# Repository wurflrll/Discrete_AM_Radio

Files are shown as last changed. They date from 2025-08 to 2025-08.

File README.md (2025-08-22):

# Discrete AM Radio

## 27MHz AM Radio from Discrete Components

# Descriptions
This project comprises two different PCBs, a Receiver and Transmitter.  The circuits rely on basic BJT amplifier designs, a 27MHz oscillator.

## Added Files
This contains all the files from my two KiCad project and the BOMS (factory assembled unlike Sawtooth generator project).

## Problems
Crystal Oscillator has issues because the loop gain is too high, due to a mispredicted Q factor of
the crystal.

Trying to use a simple op-amp circuit for the preamplification of the microphone signal was a bad idea.  
The NCS20072D is simply too high noise, especially for a high gain pre-amp from a ~-50dB microphone.

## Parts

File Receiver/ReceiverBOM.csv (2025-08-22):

Id | Designator | Footprint | Quantity | Designation | Supplier and ref
1 | R2,R21 | R_0603_1608Metric | 2 | 2.2K | C114662
2 | R12,R20 | R_0603_1608Metric | 2 | 5.1K | C105580
3 | C16 | C_Radial_D8.0mm_H11.5mm_P3.50mm | 1 | 220uF | C107639
4 | C20,C3,C17,C19,C5,C11,C15,C2,C1,C6,C4,C14,C18,C7 | C_0603_1608Metric | 14 | 10uF | C19702
5 | RV2,RV3,RV1 | Potentiometer_Bourns_3386P_Vertical | 3 | R_Potentiometer | C48642119
6 | R6,R24,R16,R13,R22,R4 | R_0603_1608Metric | 6 | 100R | C105588
7 | C10,C12 | C_0603_1608Metric | 2 | 51pF | C107051
8 | R14,R15,R7,R9,R27,R8 | R_0603_1608Metric | 6 | 10K | C98220
9 | Q3,Q6,Q7,Q8,Q4,Q1,Q9 | SOT-23 | 7 | Q_NPN_BEC | C3199172
10 | R18,R25 | R_0603_1608Metric | 2 | 100K | C14675
11 | R19,R1 | R_0603_1608Metric | 2 | 3.16K | C2930087
12 | C8,C13 | C_0603_1608Metric | 2 | 10nF | C100042
13 | R26 | R_0603_1608Metric | 1 | 22K | C31850
14 | R11 | R_0603_1608Metric | 1 | 332K | C4351218
15 | R17 | R_0603_1608Metric | 1 | 51K | C107231
16 | U2 | SOIC-8_3.9x4.9mm_P1.27mm | 1 | LM386 | C23573
17 | R10 | R_0603_1608Metric | 1 | 110K | C2906984
18 | TP3,TP2,TP4,TP5 | TestPoint_Loop_D2.50mm_Drill1.0mm | 4 | LOOP | C5199815
19 | C9 | C_0603_1608Metric | 1 | 68pF | C62782
20 | L1 | L_Axial_L12.0mm_D5.0mm_P15.24mm_Horizontal_Fastron_MISC | 1 | 4.7mH | C2931871
21 | R23 | R_0603_1608Metric | 1 | 1K | C22548
22 | U1 | SOIC-8_3.9x4.9mm_P1.27mm | 1 | NCS20072D | C89845
23 | D1 | D_SOD-123 | 1 | IN4148 | C82544

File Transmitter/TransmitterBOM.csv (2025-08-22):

Designator | Footprint | Quantity | Value | LCSC Part #
C1 | 603 | 1 | 10u | C19702
C10, C11, C14, C15, C17, C4, C5, C6, C7, C9 | 603 | 10 | 10uF | C19702
C12 | 603 | 1 | 50pF | C107231
C13, C18, C19, C8 | 603 | 4 | 10nF | C100042
C16 | C_Radial_D8.0mm_H11.5mm_P3.50mm | 1 | 220uF | C107639
C2, C3 | 603 | 2 | 51pF | C107231
D1 | D_SOD-123 | 1 | D | C83528
MK1 | POM-2244P-C3310-2-R | 1 | Microphone | C20200111
Q10, Q11, Q13, Q14, Q8, Q9 | SOT-23 | 6 | Q_NPN_BEC | C3199172
Q2 | TO-92 | 1 | 2N2222 | C118536
R1 | 603 | 1 | 110K | C14675
R10, R11, R16, R17, R6, R7 | 603 | 6 | 1K | C22548
R12, R18, R5 | 603 | 3 | 100R | C105588
R13, R15 | 603 | 2 | 15K | C114661
R14, R21, R23, R3 | 603 | 4 | 22K | C31850
R19, R20, R4 | 603 | 3 | 100K | C14675
R2 | 603 | 1 | 680K | C137690
R22, R9 | 603 | 2 | 10K | C98220
RV1, RV2 | Potentiometer_Bourns_3386P_Vertical | 2 | R_Potentiometer
TP1, TP2, TP4 | TestPoint_Loop_D2.50mm_Drill1.0mm | 3 | TestPoint
TP5, TP6 | TestPoint_Pad_D4.0mm | 2 | TestPoint
TP7, TP8 | TestPoint_Plated_Hole_D2.0mm | 2 | TestPoint
U1, U2, U3 | SOIC-8_3.9x4.9mm_P1.27mm | 3 | NCS20072D | C89845
U5 | SOIC-8_3.9x4.9mm_P1.27mm | 1 | LM386 | C23573
Y1 | Crystal_SMD_SeikoEpson_TSX3225-4Pin_3.2x2.5mm | 1 | Crystal_GND24 | C37635384

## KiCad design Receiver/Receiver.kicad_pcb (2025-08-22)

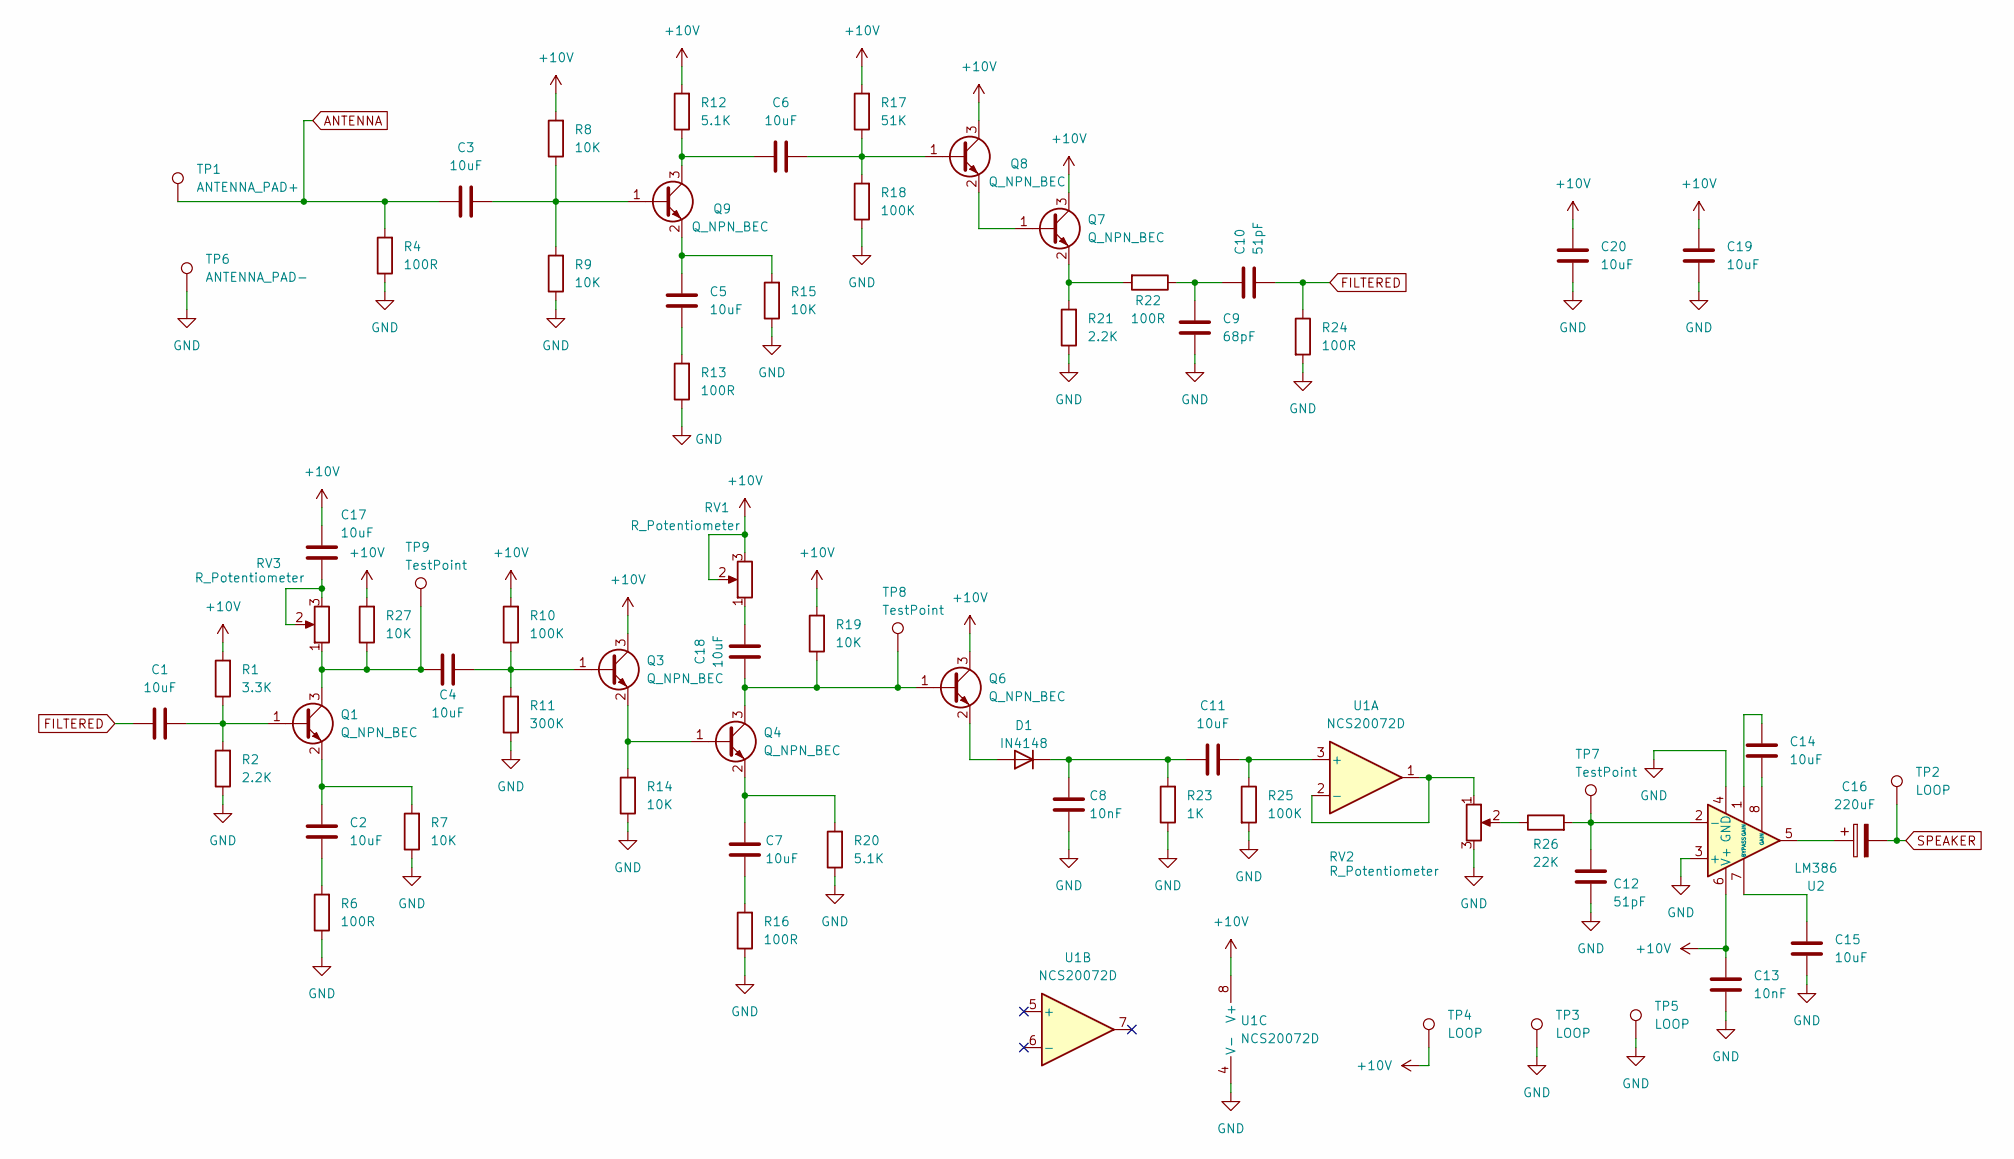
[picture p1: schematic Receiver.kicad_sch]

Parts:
C1, C2, C3, C4, C5, C6, C7, C11, C14, C15, C17, C18, C19, C20: 10uF; C_0603_1608Metric
C8, C13: 10nF; C_0603_1608Metric
C9: 68pF; C_0603_1608Metric
C10, C12: 51pF; C_0603_1608Metric
C16: 220uF; C_Radial_D8.0mm_H11.5mm_P3.50mm
D1: IN4148; D_SOD-123
Q1, Q3, Q4, Q6, Q7, Q8, Q9: Q_NPN_BEC; SOT-23
R1: 3.3K; R_0603_1608Metric
R2, R21: 2.2K; R_0603_1608Metric
R4, R6, R13, R16, R22, R24: 100R; R_0603_1608Metric
R7, R8, R9, R14, R15, R19, R27: 10K; R_0603_1608Metric
R10, R18, R25: 100K; R_0603_1608Metric
R11: 300K; R_0603_1608Metric
R12, R20: 5.1K; R_0603_1608Metric
R17: 51K; R_0603_1608Metric
R23: 1K; R_0603_1608Metric
R26: 22K; R_0603_1608Metric
RV1, RV2, RV3: R_Potentiometer; Potentiometer_Bourns_3386P_Vertical
TP1: ANTENNA_PAD+; TestPoint_Pad_D4.0mm
TP2, TP3, TP4, TP5: LOOP; TestPoint_Loop_D2.50mm_Drill1.0mm
TP6: ANTENNA_PAD-; TestPoint_Pad_D4.0mm
TP7, TP8, TP9: TestPoint; TestPoint_Plated_Hole_D2.0mm
U1: NCS20072D; SOIC-8_3.9x4.9mm_P1.27mm
U2: LM386; SOIC-8_3.9x4.9mm_P1.27mm

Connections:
+10V: C13.1, C17.2, C19.2, C20.2, Q3.3 (C), Q6.3 (C), Q7.3 (C), Q8.3 (C), R1.2, R8.2, R10.2, R12.2, R17.2, R19.2, R27.2, RV1.2, RV1.3, TP4.1, U1.8 (V+), U2.6 (V+)
ANTENNA: C3.1, R4.2, TP1.1
FILTERED: C1.1, C10.2, R24.1
GND: C8.1, C9.2, C12.2, C13.2, C15.1, C19.1, C20.1, R2.1, R4.1, R6.1, R7.1, R9.1, R11.1, R13.1, R14.1, R15.1, R16.1, R18.1, R20.1, R21.1, R23.1, R24.2, R25.2, RV2.3, TP3.1, TP5.1, TP6.1, U1.4 (V-), U2.3 (+), U2.4 (GND)
unnamed: C2.1, R6.2
unnamed: C5.1, R13.2
unnamed: C7.1, R16.2
unnamed: C9.1, C10.1, R22.1
unnamed: C14.1, U2.8 (GAIN)
unnamed: C14.2, U2.1 (GAIN)
unnamed: C16.1, U2.5
unnamed: C17.1, RV3.2, RV3.3
unnamed: C18.1, RV1.1
unnamed: D1.2 (A), Q6.2 (E)
unnamed: C8.2, C11.1, D1.1 (K), R23.2
unnamed: C1.2, Q1.1 (B), R1.1, R2.2
unnamed: C4.2, Q1.3 (C), R27.1, RV3.1, TP9.1
unnamed: C2.2, Q1.2 (E), R7.2
unnamed: C4.1, Q3.1 (B), R10.1, R11.2
unnamed: Q3.2 (E), Q4.1 (B), R14.2
unnamed: C18.2, Q4.3 (C), Q6.1 (B), R19.1, TP8.1
unnamed: C7.2, Q4.2 (E), R20.2
unnamed: Q7.1 (B), Q8.2 (E)
unnamed: Q7.2 (E), R21.2, R22.2
unnamed: C6.1, Q8.1 (B), R17.1, R18.2
unnamed: C3.2, Q9.1 (B), R8.1, R9.2
unnamed: C6.2, Q9.3 (C), R12.1
unnamed: C5.2, Q9.2 (E), R15.2
unnamed: R26.1, RV2.2
unnamed: C11.2, R25.1, U1.3 (+)
unnamed: RV2.1, U1.1, U1.2 (-)
unnamed: C12.1, R26.2, TP7.1, U2.2 (-)
unnamed: C15.2, U2.7 (BYPASS)
SPEAKER: C16.2, TP2.1

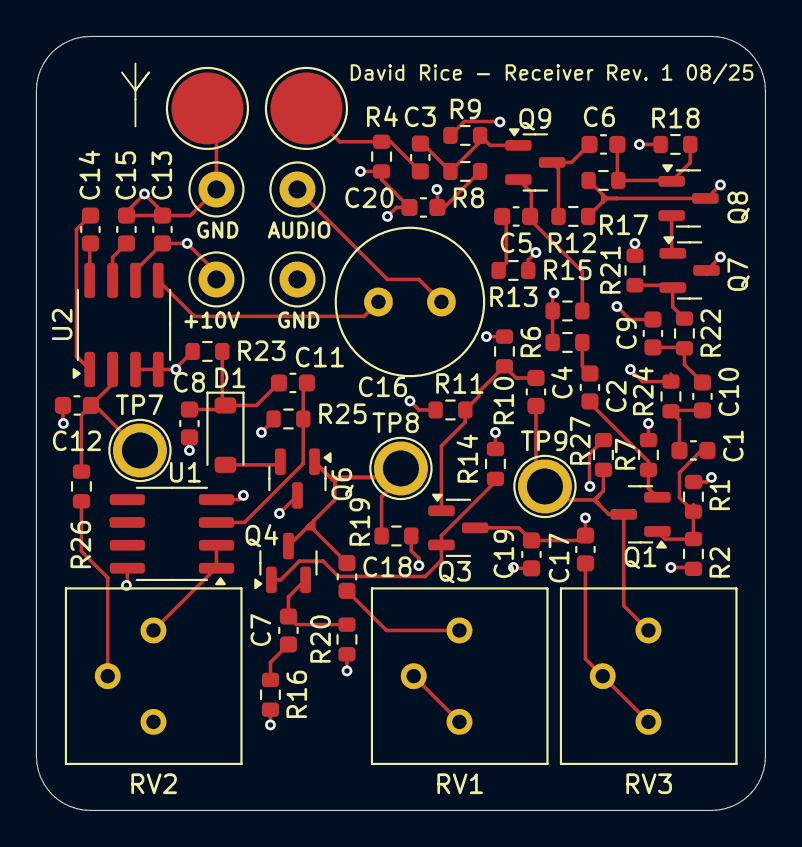
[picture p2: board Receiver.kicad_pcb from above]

Board: 2 copper layers, 40.5 x 43.0 mm, 67 parts (0 on the bottom side), 34 nets.

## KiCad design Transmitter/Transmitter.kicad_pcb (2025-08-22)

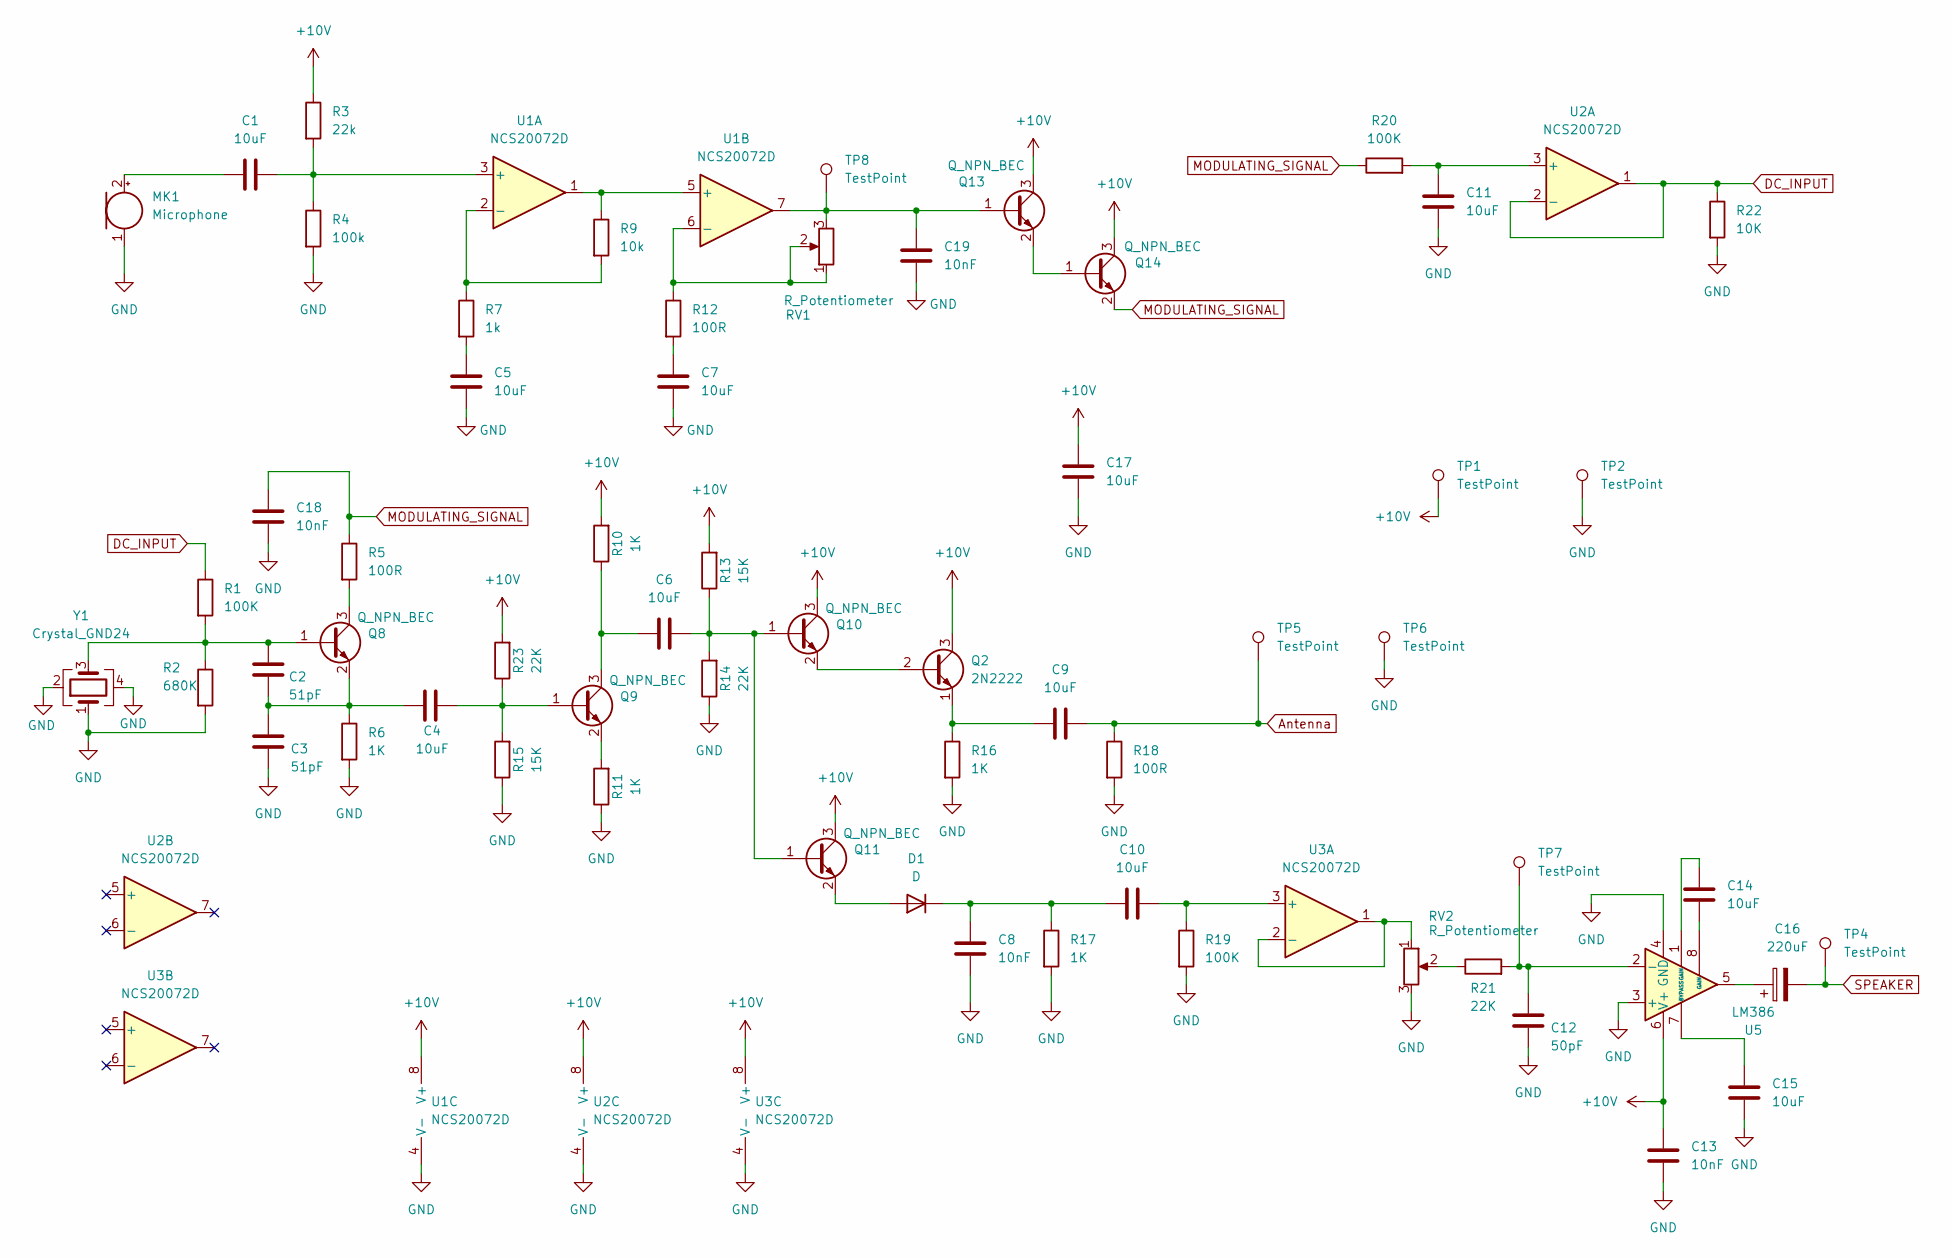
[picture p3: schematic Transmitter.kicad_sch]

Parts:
C1, C4, C5, C6, C7, C9, C10, C11, C14, C15, C17: 10uF; C_0603_1608Metric
C2, C3: 51pF; C_0603_1608Metric
C8, C13, C18, C19: 10nF; C_0603_1608Metric
C12: 50pF; C_0603_1608Metric
C16: 220uF; C_Radial_D8.0mm_H11.5mm_P3.50mm
D1: D; D_SOD-123
MK1: Microphone; POM-2244P-C3310-2-R
Q2: 2N2222; TO-92
Q8, Q9, Q10, Q11, Q13, Q14: Q_NPN_BEC; SOT-23
R1, R19, R20: 100K; R_0603_1608Metric
R2: 680K; R_0603_1608Metric
R3: 22k; R_0603_1608Metric
R4: 100k; R_0603_1608Metric
R5, R12, R18: 100R; R_0603_1608Metric
R6, R10, R11, R16, R17: 1K; R_0603_1608Metric
R7: 1k; R_0603_1608Metric
R9: 10k; R_0603_1608Metric
R13, R15: 15K; R_0603_1608Metric
R14, R21, R23: 22K; R_0603_1608Metric
R22: 10K; R_0603_1608Metric
RV1, RV2: R_Potentiometer; Potentiometer_Bourns_3386P_Vertical
TP1, TP2, TP4: TestPoint; TestPoint_Loop_D2.50mm_Drill1.0mm
TP5, TP6: TestPoint; TestPoint_Pad_D4.0mm
TP7, TP8: TestPoint; TestPoint_Plated_Hole_D2.0mm
U1, U2, U3: NCS20072D; SOIC-8_3.9x4.9mm_P1.27mm
U5: LM386; SOIC-8_3.9x4.9mm_P1.27mm
Y1: Crystal_GND24; Crystal_SMD_SeikoEpson_TSX3225-4Pin_3.2x2.5mm

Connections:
+10V: C13.1, C17.2, Q2.3 (C), Q10.3 (C), Q11.3 (C), Q13.3 (C), Q14.3 (C), R3.1, R10.2, R13.2, R23.2, TP1.1, U1.8 (V+), U2.8 (V+), U3.8 (V+), U5.6 (V+)
Antenna: C9.2, R18.1, TP5.1
DC_INPUT: R1.1, R22.1, U2.1, U2.2 (-)
GND: C3.2, C5.2, C7.2, C8.2, C11.2, C12.2, C13.2, C15.1, C17.1, C18.2, C19.2, MK1.1 (-), R2.2, R4.2, R6.2, R11.1, R14.1, R15.1, R16.2, R17.2, R18.2, R19.2, R22.2, RV2.3, TP2.1, TP6.1, U1.4 (V-), U2.4 (V-), U3.4 (V-), U5.3 (+), U5.4 (GND), Y1.1, Y1.2, Y1.4
MODULATING_SIGNAL: C18.1, Q14.2 (E), R5.1, R20.1
unnamed: C5.1, R7.2
unnamed: C7.1, R12.2
unnamed: C14.1, U5.8 (GAIN)
unnamed: C14.2, U5.1 (GAIN)
unnamed: C16.1, U5.5
unnamed: D1.2 (A), Q11.2 (E)
unnamed: C8.1, C10.1, D1.1 (K), R17.1
unnamed: C1.1, MK1.2 (+)
unnamed: C9.1, Q2.1 (E), R16.1
unnamed: C2.1, Q8.1 (B), R1.2, R2.1, Y1.3
unnamed: Q8.3 (C), R5.2
unnamed: C2.2, C3.1, C4.2, Q8.2 (E), R6.1
unnamed: C4.1, Q9.1 (B), R15.2, R23.1
unnamed: C6.2, Q9.3 (C), R10.1
unnamed: Q9.2 (E), R11.2
unnamed: C6.1, Q10.1 (B), Q11.1 (B), R13.1, R14.2
unnamed: Q2.2 (B), Q10.2 (E)
unnamed: C19.1, Q13.1 (B), RV1.3, TP8.1, U1.7
unnamed: Q13.2 (E), Q14.1 (B)
unnamed: R21.1, RV2.2
unnamed: C1.2, R3.2, R4.1, U1.3 (+)
unnamed: R7.1, R9.2, U1.2 (-)
unnamed: R9.1, U1.1, U1.5 (+)
unnamed: R12.1, RV1.1, RV1.2, U1.6 (-)
unnamed: C11.1, R20.2, U2.3 (+)
unnamed: C10.2, R19.1, U3.3 (+)
unnamed: RV2.1, U3.1, U3.2 (-)
unnamed: C12.1, R21.2, TP7.1, U5.2 (-)
unnamed: C15.2, U5.7 (BYPASS)
SPEAKER: C16.2, TP4.1

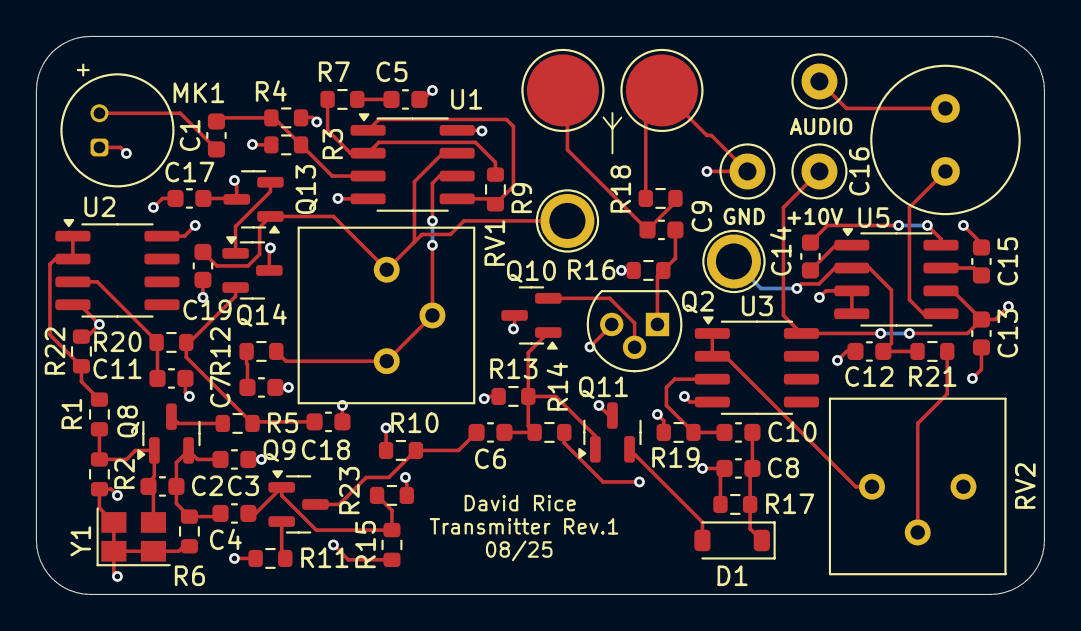
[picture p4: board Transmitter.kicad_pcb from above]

Board: 2 copper layers, 56.0 x 31.0 mm, 64 parts (0 on the bottom side), 35 nets.
